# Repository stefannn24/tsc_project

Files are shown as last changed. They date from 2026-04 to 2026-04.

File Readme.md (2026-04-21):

InkTime Smartwatch

Hardware Functionality
Power Management

The power path begins at the USB-C connector (5V VBUS), which feeds the Li-Po charge management IC. This IC handles the safe charging cycle for the 250mAh battery. To ensure the MCU and E-paper display receive a clean and stable voltage even as the battery discharges, a DC/DC Buck/Boost regulator is utilized to provide a constant 3.3V system rail.
Compute & Connectivity

The system is driven by the nRF52840 SoC. It manages:

- I2C Bus: Used for communicating with the ultra-low-power IMU (Accelerometer).
- SPI Bus: Dedicated specifically to the E-paper display to ensure enough bandwidth for screen refreshes without interrupting other peripherals.
- USB: Routed directly to the nRF52840 for potential firmware flashing and USB-CDC communications.
- RF: A 50-ohm matched RF trace connects the MCU to a 2.4GHz Johanson SMD chip antenna for Bluetooth Low Energy (BLE) connectivity.

Peripherals

- Display: A low-power E-paper display module.
- IMU: An accelerometer is used for hardware-level step counting.
- Haptics

During the layout and routing phases of the PCB, several specific design rules and constraints were strictly applied to ensure manufacturability and signal integrity:

- Strict top-layer placement: To comply with manufacturing assembly constraints, 100% of the components were placed exclusively on the Top layer.
- Trace width constraints for power: All power delivery networks (VCC, VBUS, 3V3, VBAT) were manually routed using a minimum trace width of 0.3mm. This ensures adequate current handling, especially during peak loads from the shaker motor. Data signals were routed at 0.15mm.
- Antenna keepout zone: The 2.4GHz SMD antenna was placed strictly on the outer edge of the PCB. A complete keepout area was enforced underneath the antenna on all layers.
- Decoupling proximity: All 100nF (0201 package) decoupling capacitors were placed as physically close to the nRF52840 and IMU power pins as mechanically possible to filter out high-frequency switching noise.

(The complete machine-readable .bom and .cpl files are located in the /Manufacturing directory).

License
This project is licensed under the MIT License. See the LICENSE file for details.

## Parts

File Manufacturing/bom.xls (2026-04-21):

Comment | Designator | Footprint | JLCPCB Part#(optional)
1uF/50V | C15, C29, C30, C31, C32, C37, C38, EPD_C1, EPD_C2, EPD_C5, EPD_C6, EPD_C7, EPD_C8, EPD_C9, EPD_C10, EPD_C11, EPD_C12 | 0402 | C1518208
4.7uF/25V | C6, C14, C20, C21, C43, C2-EP-DR | 0402 | C5718966
10uF/25V | C1-EP-DR, C39 | 0603 | C344022
10uF/6.3V | C24 | 0402 | C76991
22uF/10V | C25, C33 | 0603 | C84419
100nF/25V | C5, C7, C8, C12, C19, C23, C27, C34, C42 | 0201 | C76939
100pF/50V | C11 | 0201 | C76922
47nF/16V | C16 | 0201 | C88917
12pF/50V | C1, C2, C17, C18 | 0201 | C384960
1pf/50V | C3, C4 | 0201 | C161411
0Ω | R2, R3, R4 | 0201 | C106227
470mΩ | R1_EP_DR | 0201 | C4327454
2.2Ω | R_TYPE_SEL | 0201 | C138154
3.3KΩ | R17, R18 | 0201 | C851731
5.1KΩ | R1_USB, R2_USB | 0201 | C852257
10KΩ | R5, R7, R8, R9, R2_EP_DR, R_PWR_EPD | 0201 | C1882653
470nH | L7 | 2520 | C5832368
3.9nH | L1 | 0201 | C77115
10uH | L2 | 0603 | C275361
15nH | L3 | 0402 | C576527
68uH | L5 | SMD, 4.8x4.8mm | C2045671
USBLC6-2SC6Y | D3 | SOT-23-6L | C2969755
KH-TYPE-C-16P | J4 | SMD | C709357
5034802400 | J1 | SMD, P=0.5mm | C122434
MAX17048G+T10 | U3 | DFN-8-EP(2x2) | C2682616
EVPAKE31A | SW_UP, SW_ENT, SW_DN | SMD,3.9x2.9mm | C569760
DRV2605YZFR | IC2 | DSBGA-9 | C81079
DMG2305UX-7 | Q1 | SOT-23 | C150470
SI1308EDL-T1-GE3 | Q3 | SOT-323 | C469327
MBR0530 | D2, D4, D5 | SOD-123 | C699108
BMA421 | IC3 | LGA-12(2x2) | C5242966
RT6160AWSC | IC9 | WLCSP-15B(2.3x1.4) | C7065276
BQ25180YBGR | IC1 | DSBGA-8(1.1x1.6) | C3682423
2450AT18B100E | ANT1 | 1206 | C2917717
NRF52840-QIAA-R | U1 | AQFN-73-EP(7x7) | C190794
X1A0000910005 | X2 | SMD3215-2P | C255869
Q22FA12800025 | X1 | SMD2016-4P | C187794

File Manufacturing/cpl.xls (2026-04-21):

ANT1 | 42.80 | 18.10 | 0.00 | 2450AT18B100E | 2450AT18B100E_ANTC3216X140N
C1 | 32.90 | 23.20 | 90.00 | 12pF | NORDIC_NRF_3_RESC0201_N
C1-EP-DR | 20.60 | 21.50 | 90.00 | 10uF | NORDIC_NRF_3_RESC0402_N
C10 | 35.00 | 18.10 | 180.00 | N.C. | NORDIC_NRF_3_RESC0201_N
C11 | 34.80 | 19.30 | 180.00 | 100pF | NORDIC_NRF_3_RESC0201_N
C12 | 32.40 | 20.80 | 270.00 | 100nF | NORDIC_NRF_3_RESC0201_N
C13 | 31.20 | 20.80 | 270.00 | N.C. | NORDIC_NRF_3_RESC0201_N
C14 | 25.70 | 21.50 | 270.00 | 4.7uF | NORDIC_NRF_3_RESC0402_N
C15 | 30.50 | 22.40 | 0.00 | 1uF | NORDIC_NRF_3_RESC0402_N
C16 | 30.40 | 21.10 | 270.00 | 47nF | NORDIC_NRF_3_RESC0201_N
C17 | 23.00 | 17.60 | 0.00 | 12pF | NORDIC_NRF_3_RESC0201_N
C18 | 23.30 | 15.90 | 0.00 | 12pF | NORDIC_NRF_3_RESC0201_N
C19 | 19.40 | 9.70 | 0.00 | 100nF | NORDIC_NRF_3_RESC0201_N
C2 | 36.50 | 19.80 | 0.00 | 12pF | NORDIC_NRF_3_RESC0201_N
C2-EP-DR | 14.40 | 25.50 | 270.00 | 4.7uF/25V | NORDIC_NRF_3_RESC0402_N
C20 | 25.20 | 12.80 | 180.00 | 4.7uF | NORDIC_NRF_3_RESC0402_N
C21 | 27.40 | 11.40 | 270.00 | 1uF | NORDIC_NRF_3_RESC0402_N
C22 | 39.70 | 18.30 | 90.00 | N.C. | NORDIC_NRF_3_RESC0201_N
C23 | 23.10 | 25.70 | 180.00 | 0.1uF | NORDIC_NRF_3_RESC0201_N
C24 | 21.10 | 25.70 | 0.00 | 10uF | NORDIC_NRF_3_RESC0402_N
C25 | 18.70 | 22.80 | 90.00 | 22uF | NORDIC_NRF_3_RESC0603_N
C27 | 13.70 | 29.90 | 90.00 | 0.1uF | NORDIC_NRF_3_RESC0201_N
C29 | 11.80 | 5.70 | 0.00 | 1uF | NORDIC_NRF_3_RESC0402_N
C3 | 35.30 | 16.90 | 180.00 | 1pF | NORDIC_NRF_3_RESC0201_N
C30 | 34.10 | 5.90 | 180.00 | 1uF | NORDIC_NRF_3_RESC0402_N
C31 | 23.10 | 5.60 | 180.00 | 1uF | NORDIC_NRF_3_RESC0402_N
C32 | 23.50 | 9.70 | 180.00 | 1uF | NORDIC_NRF_3_RESC0402_N
C33 | 22.20 | 19.70 | 270.00 | 22uF | NORDIC_NRF_3_RESC0603_N
C34 | 19.20 | 8.50 | 180.00 | 0.1uF | NORDIC_NRF_3_RESC0201_N
C37 | 14.20 | 28.10 | 180.00 | 1uF | NORDIC_NRF_3_RESC0402_N
C38 | 17.40 | 24.20 | 270.00 | 1uF | NORDIC_NRF_3_RESC0402_N
C39 | 16.10 | 25.60 | 270.00 | 10uF | NORDIC_NRF_3_RESC0603_N
C4 | 38.60 | 17.10 | 90.00 | 1pF | NORDIC_NRF_3_RESC0201_N
C42 | 25.40 | 27.00 | 270.00 | 0.1uF | NORDIC_NRF_3_RESC0201_N
C43 | 20.30 | 27.00 | 180.00 | 4.7uF | NORDIC_NRF_3_RESC0402_N
C5 | 24.70 | 19.60 | 180.00 | 100nF | NORDIC_NRF_3_RESC0201_N
C6 | 25.10 | 14.20 | 180.00 | 4.7uF | NORDIC_NRF_3_RESC0402_N
C7 | 30.30 | 11.90 | 270.00 | 100nF | NORDIC_NRF_3_RESC0201_N
C8 | 31.50 | 12.00 | 270.00 | 100nF | NORDIC_NRF_3_RESC0201_N
C9 | 34.90 | 15.70 | 180.00 | 820pF | NORDIC_NRF_3_RESC0201_N
D2 | 17.60 | 17.50 | 270.00 | MBR0530 | ESP32_C6_LIBRARY_5_SOD3716X135N
D3 | 23.30 | 31.50 | 0.00 | USBLC6-2SC6Y | ESP32_C6_LIBRARY_3_SOT95P280X145-6N
D4 | 15.90 | 20.60 | 90.00 | MBR0530 | ESP32_C6_LIBRARY_5_SOD3716X135N
D5 | 16.20 | 14.00 | 90.00 | MBR0530 | ESP32_C6_LIBRARY_5_SOD3716X135N
EPD_C1 | 13.70 | 20.00 | 180.00 | 1uF/50V | NORDIC_NRF_3_RESC0402_N
EPD_C10 | 12.90 | 10.50 | 180.00 | 1uF/50V | NORDIC_NRF_3_RESC0402_N
EPD_C11 | 12.90 | 9.10 | 180.00 | 1uF/50V | NORDIC_NRF_3_RESC0402_N
EPD_C12 | 10.80 | 10.10 | 90.00 | 1uF/50V | NORDIC_NRF_3_RESC0402_N
EPD_C2 | 13.70 | 21.30 | 180.00 | 1uF/50V | NORDIC_NRF_3_RESC0402_N
EPD_C5 | 13.00 | 17.00 | 180.00 | 0.1uF/50V | NORDIC_NRF_3_RESC0402_N
EPD_C6 | 13.00 | 15.70 | 180.00 | 1uF/50V | NORDIC_NRF_3_RESC0402_N
EPD_C7 | 13.00 | 14.40 | 180.00 | 1uF/50V | NORDIC_NRF_3_RESC0402_N
EPD_C8 | 13.00 | 13.10 | 180.00 | 1uF/50V | NORDIC_NRF_3_RESC0402_N
EPD_C9 | 12.90 | 11.80 | 180.00 | 1uF/50V | NORDIC_NRF_3_RESC0402_N
IC1 | 17.20 | 26.30 | 180.00 | BQ25180YBGR | BQ25180YBGR_BGA8C40P2X4_100X155X50
IC2 | 21.20 | 9.30 | 270.00 | DRV2605YZFR | DRV2605YZFR_BGA9C50P3X3_144X144X62
IC3 | 19.75 | 11.85 | 90.00 | BMA421 | BMA423_BMA423
IC9 | 22.60 | 23.85 | 0.00 | RT6160AWSC_RT6160AWSC | RT6160AWSC_BGA15C40P3X5_140X230X60
J1 | 9.30 | 17.25 | 270.00 | 503480-2400 | 503480-2400_5034802400
J2 | 41.52 | 8.70 | 0.00 | TC2030-IDC_TC2030-IDC | TC2030-IDC_TC2030IDC
J4 | 23.00 | 30.94 | 180.00 | KH-TYPE-C-16P | KH-TYPE-C-16P_KINGHELM_KH-TYPE-C-16P
L1 | 37.70 | 18.60 | 0.00 | 3.9nH | NORDIC_NRF_2_RESC0402_L
L2 | 27.90 | 21.10 | 90.00 | 10uH | NORDIC_NRF_2_RESC0603_N
L3 | 27.50 | 23.70 | 0.00 | 15nH | NORDIC_NRF_2_RESC0402_L
L5 | 6.50 | 30.55 | 0.00 | 68uH | ESP32_C6_LIBRARY_2_IND_4828-WE-TPC_WRE
L7 | 27.30 | 25.90 | 270.00 | FTC252012SR47MBCA | MLP2016SR47MT0S1_INDC2016X100N
Q1 | 32.65 | 29.40 | 270.00 | 20V/4.2A/52mΩ/1.4W | ESP32_C6_LIBRARY_4_ESP32_C6_LIBRARY_4_ESP32_C6_LIBRARY_4_ESP32_C6_LIBRARY_4_ESP32_WROVER_SPARKFUN-DISCRETESEMI_SOT23-3
Q3 | 13.50 | 23.40 | 0.00 | SI1308EDL-T1-GE3 | ESP32_C6_LIBRARY_6_SOT65P210X110-3N
R17 | 20.85 | 14.90 | 0.00 | 3K3 | CPF0201D7K68C1_0201
R18 | 19.10 | 15.50 | 0.00 | 3K3 | CPF0201D7K68C1_0201
R1_EP_DR | 5.10 | 26.30 | 0.00 | 0.47 | CPF0201D7K68C1_0201
R1_USB | 24.10 | 27.20 | 270.00 | 5K1 | CPF0201D7K68C1_0201
R2 | 21.70 | 22.10 | 0.00 | 0 | CPF0201D7K68C1_0201
R2_EP_DR | 3.90 | 26.00 | 0.00 | 10k | CPF0201D7K68C1_0201
R2_USB | 22.60 | 27.20 | 90.00 | 5K1 | CPF0201D7K68C1_0201
R3 | 21.80 | 10.75 | 270.00 | 0 | CPF0201D7K68C1_0201
R4 | 21.05 | 23.90 | 0.00 | 0 | CPF0201D7K68C1_0201
R5 | 32.30 | 6.10 | 180.00 | 10K | CPF0201D7K68C1_0201
R7 | 11.80 | 6.90 | 90.00 | 10K | CPF0201D7K68C1_0201
R8 | 20.30 | 4.40 | 0.00 | 10K | CPF0201D7K68C1_0201
R9 | 16.90 | 28.00 | 90.00 | 10k | CPF0201D7K68C1_0201
R_PWR_EPD | 29.70 | 29.00 | 270.00 | 10k | CPF0201D7K68C1_0201
R_TYPE_SEL | 6.40 | 26.40 | 180.00 | 2.2 | CPF0201D7K68C1_0201
SJ1 | 9.10 | 26.10 | 180.00 |  | ESP32_C6_LIBRARY_7_JUMPER_SJ
SW_DN | 12.00 | 3.37 | 180.00 | 2025-10-22_07-23-44_LIBRARY_EVP-AKE31ASW_EVP-AKE31A_PAN | 2025-10-22_07-23-44_LIBRARY_SW_EVP-AKE31A_PAN
SW_ENT | 23.00 | 3.37 | 180.00 | 2025-10-22_07-23-44_LIBRARY_EVP-AKE31ASW_EVP-AKE31A_PAN | 2025-10-22_07-23-44_LIBRARY_SW_EVP-AKE31A_PAN
SW_UP | 34.00 | 3.37 | 180.00 | 2025-10-22_07-23-44_LIBRARY_EVP-AKE31ASW_EVP-AKE31A_PAN | 2025-10-22_07-23-44_LIBRARY_SW_EVP-AKE31A_PAN
TP_3.3V1 | 23.70 | 21.50 | 0.00 | HECTOR_WATCH_1_TPTP20R | HECTOR_WATCH_1_TP20R
TP_3V1 | 18.95 | 17.50 | 0.00 | HECTOR_WATCH_1_TPTP20R | HECTOR_WATCH_1_TP20R
TP_BAT_GND | 15.90 | 32.40 | 0.00 | HECTOR_WATCH_1_TPTP20R | HECTOR_WATCH_1_TP20R
TP_GND | 28.90 | 6.25 | 180.00 | HECTOR_WATCH_1_TPTP20R | HECTOR_WATCH_1_TP20R
TP_ON | 20.60 | 7.10 | 180.00 | HECTOR_WATCH_1_TPTP20R | HECTOR_WATCH_1_TP20R
TP_OP | 23.10 | 7.70 | 180.00 | HECTOR_WATCH_1_TPTP20R | HECTOR_WATCH_1_TP20R
TP_RESET1 | 29.00 | 9.35 | 0.00 | HECTOR_WATCH_1_TPTP20R | HECTOR_WATCH_1_TP20R
TP_SCL1 | 21.30 | 16.70 | 0.00 | HECTOR_WATCH_1_TPTP20R | HECTOR_WATCH_1_TP20R
TP_SDA1 | 31.85 | 25.70 | 0.00 | HECTOR_WATCH_1_TPTP20R | HECTOR_WATCH_1_TP20R
TP_SWDCLK1 | 37.10 | 14.65 | 0.00 | HECTOR_WATCH_1_TPTP20R | HECTOR_WATCH_1_TP20R
TP_SWDIO1 | 34.95 | 13.10 | 180.00 | HECTOR_WATCH_1_TPTP20R | HECTOR_WATCH_1_TP20R
TP_SWO1 | 33.35 | 10.75 | 0.00 | HECTOR_WATCH_1_TPTP20R | HECTOR_WATCH_1_TP20R
TP_VBAT | 16.20 | 29.70 | 0.00 | HECTOR_WATCH_1_TPTP20R | HECTOR_WATCH_1_TP20R
TP_VREG | 24.70 | 23.95 | 0.00 | HECTOR_WATCH_1_TPTP20R | HECTOR_WATCH_1_TP20R
U1 | 30.10 | 16.35 | 0.00 | NRF52840_QF | NORDIC_NRF_4_AQFN50P700X700X85_HS-74N
U3 | 11.50 | 31.50 | 180.00 | MAX17048G+T10 | ESP32_C6_LIBRARY_SON50P200X200X80-9N
X1 | 34.70 | 21.80 | 270.00 | 32MHZ | NORDIC_NRF_BT-XTAL_2016_N
X2\ | 25.30 | 16.95 | 270.00 | 32.768kHz | NORDIC_NRF_1_XTAL_3215_N

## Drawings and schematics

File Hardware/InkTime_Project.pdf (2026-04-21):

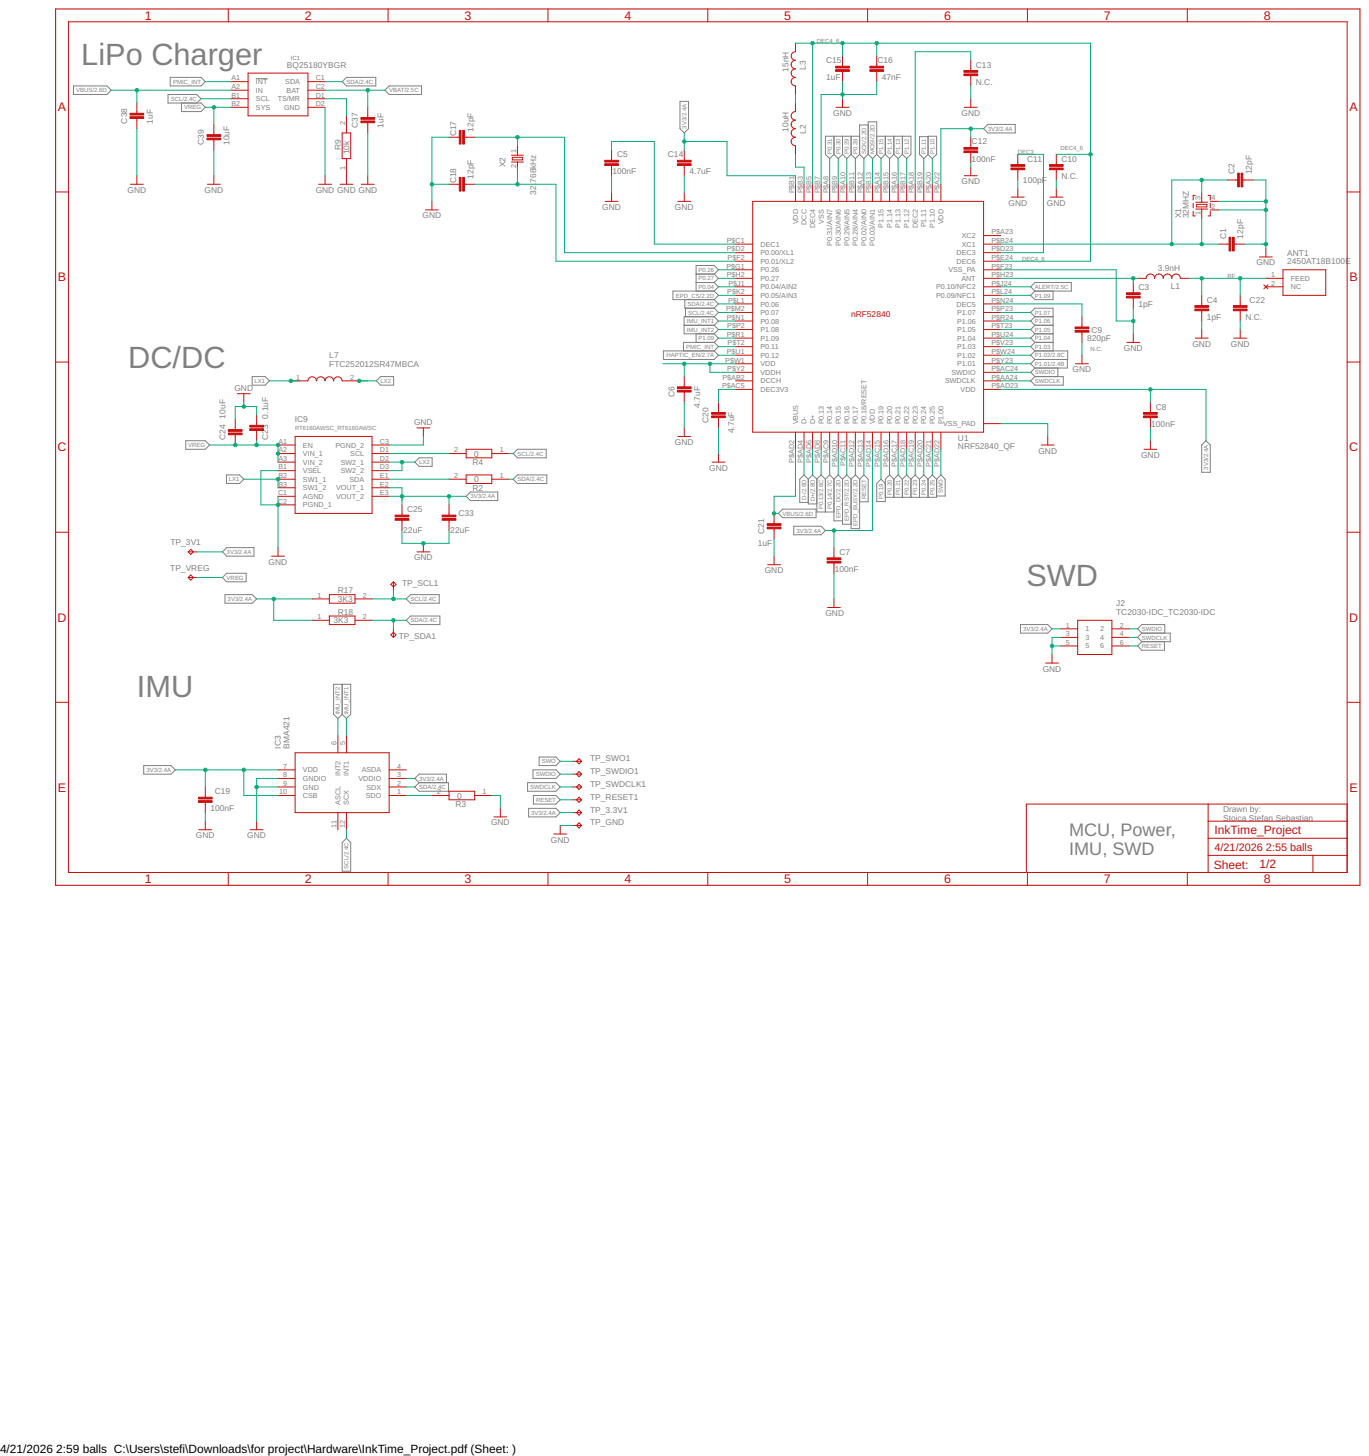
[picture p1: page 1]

4/21/2026 2:59 balls C:\Users\stefi\Downloads\for project\Hardware\InkTime_Project.pdf (Sheet: )

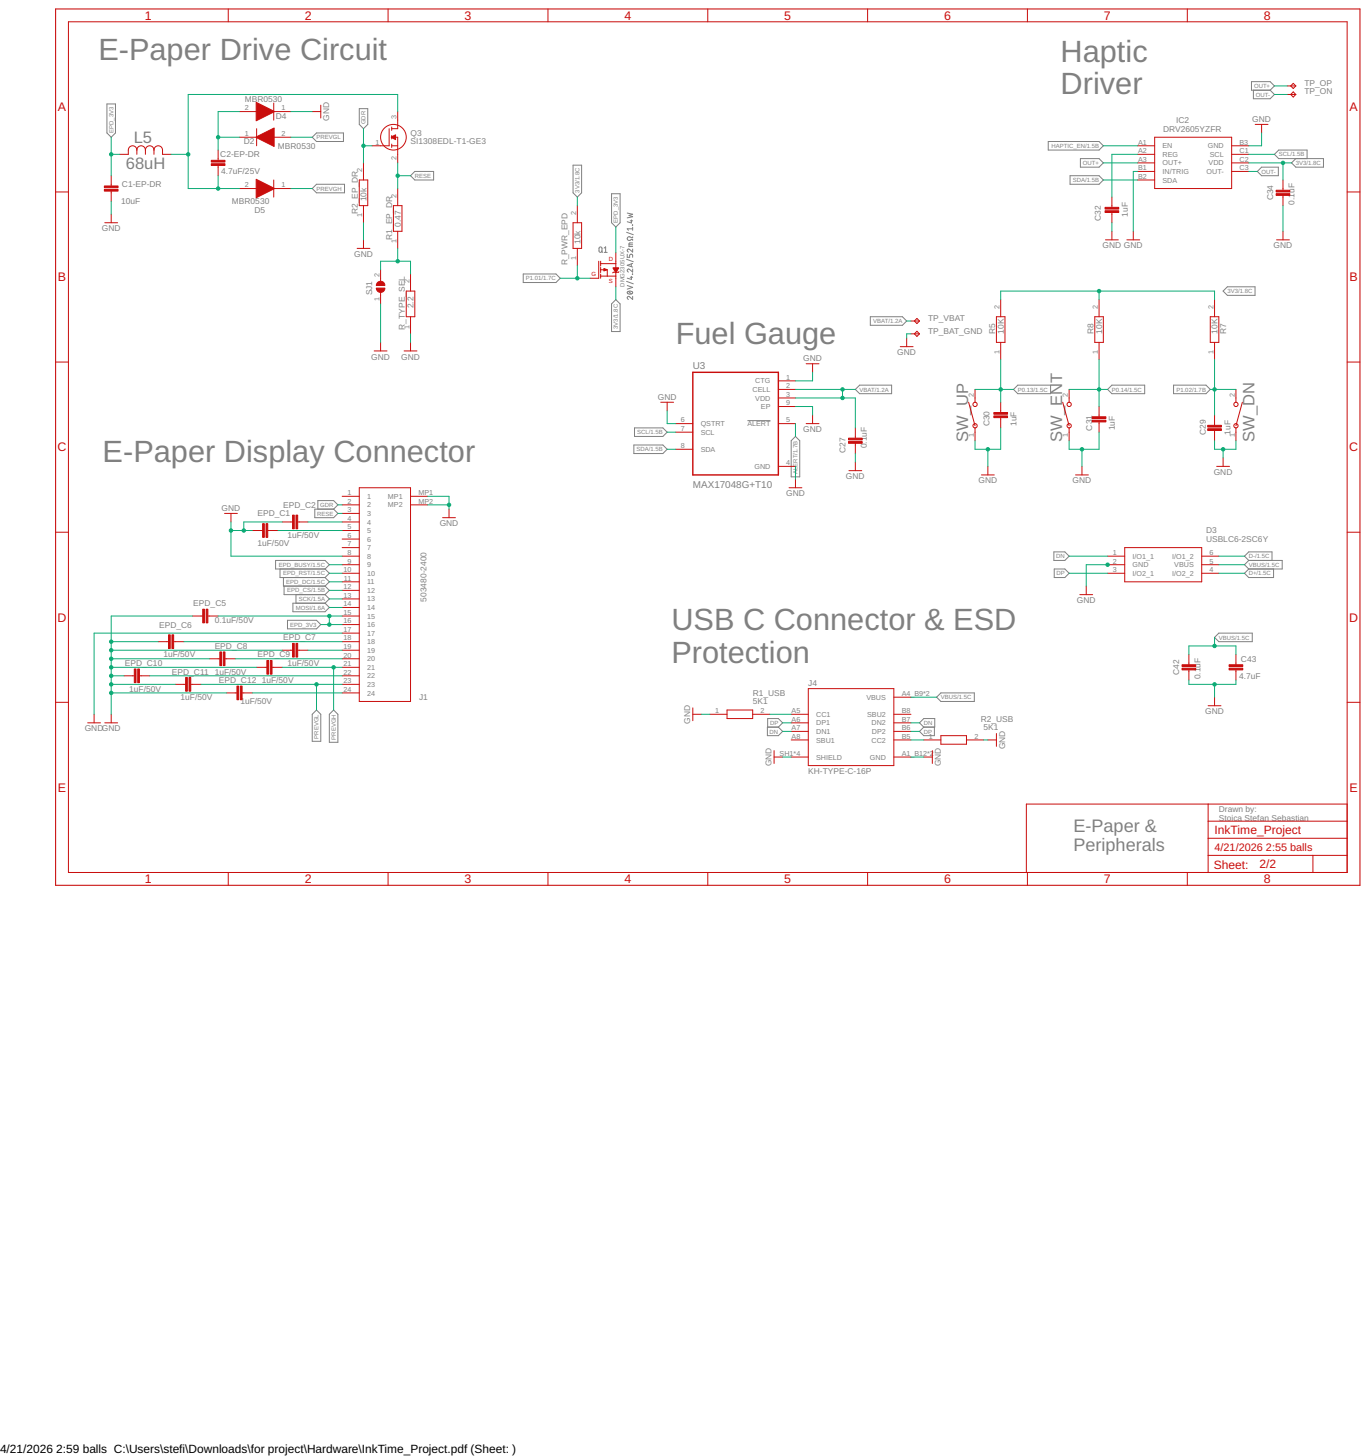
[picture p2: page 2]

EPD_C7 18

EPD_C8 | 19

1uF/50V | EPD_C9 | 20
EPD_C11 1uF/50V | | 22

EPD_C10 | | 1uF/50V 21

EPD_C12 1uF/50V | 23

4/21/2026 2:59 balls C:\Users\stefi\Downloads\for project\Hardware\InkTime_Project.pdf (Sheet: )

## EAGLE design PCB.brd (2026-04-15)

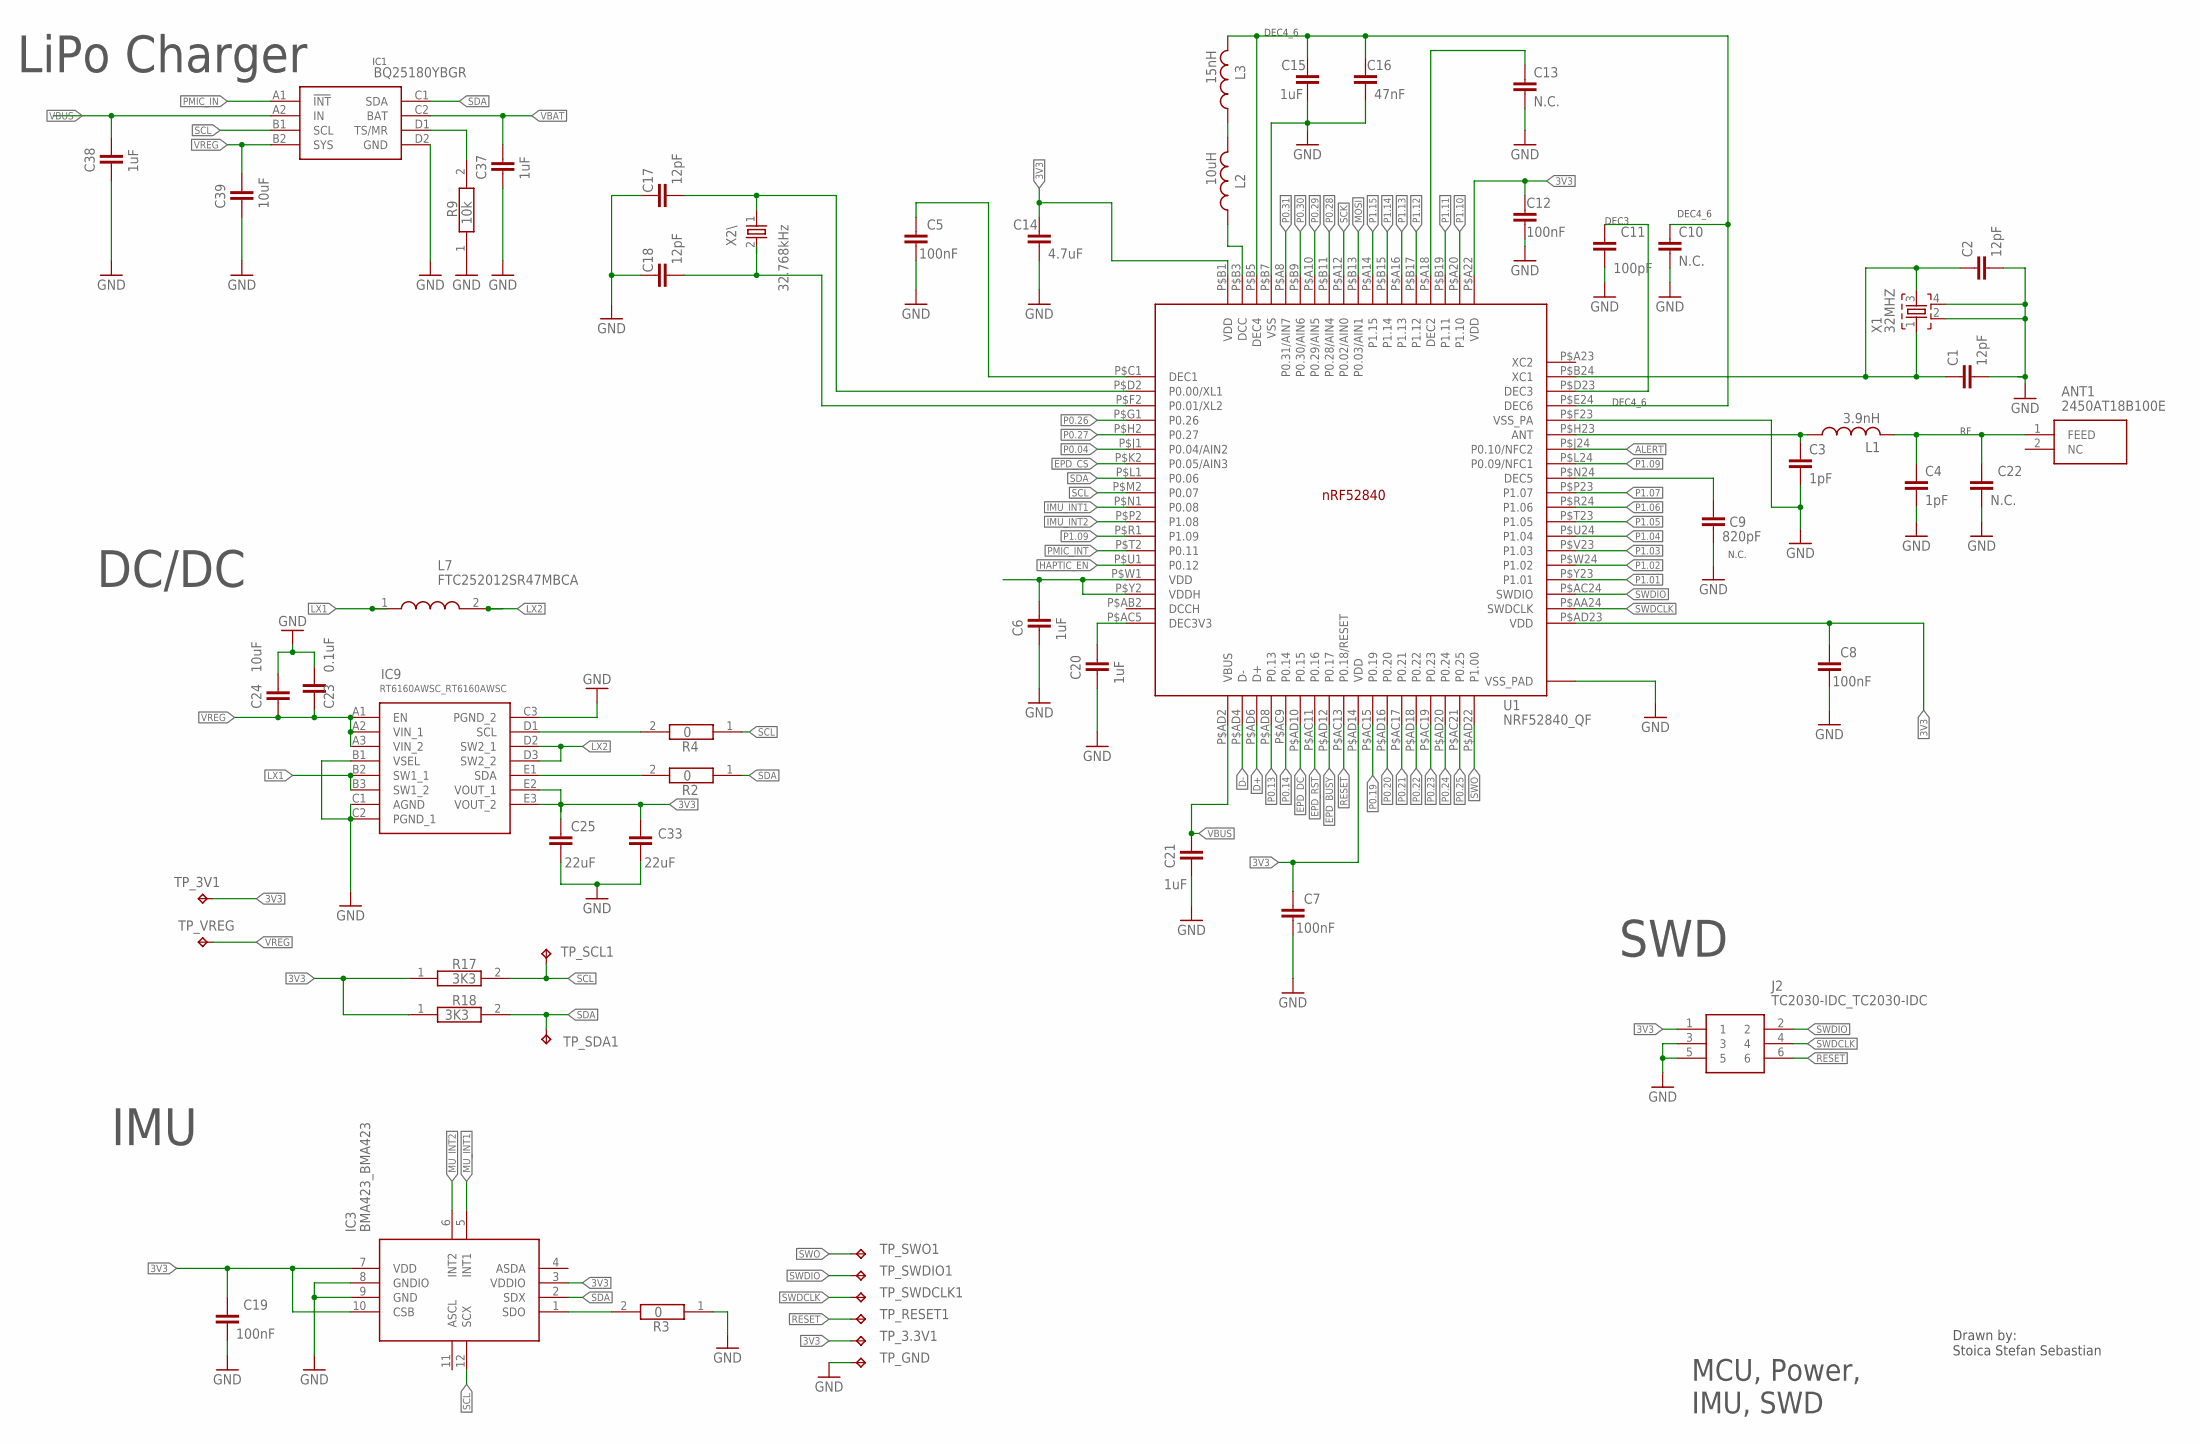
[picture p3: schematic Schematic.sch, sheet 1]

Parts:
ANT1: 2450AT18B100E; 2450AT18B100E_ANTC3216X140N
C1, C2, C17, C18: 12pF; NORDIC_NRF_3_RESC0201_N
C3, C4: 1pF; NORDIC_NRF_3_RESC0201_N
C5, C7, C8, C12, C19: 100nF; NORDIC_NRF_3_RESC0201_N
C6, C15, C20, C21, C37, C38: 1uF; NORDIC_NRF_3_RESC0402_N
C9: 820pF; NORDIC_NRF_3_RESC0201_N
C10, C13, C22: N.C.; NORDIC_NRF_3_RESC0201_N
C11: 100pF; NORDIC_NRF_3_RESC0201_N
C14: 4.7uF; NORDIC_NRF_3_RESC0402_N
C16: 47nF; NORDIC_NRF_3_RESC0201_N
C23: 0.1uF; NORDIC_NRF_3_RESC0201_N
C24, C39: 10uF; NORDIC_NRF_3_RESC0402_N
C25, C33: 22uF; NORDIC_NRF_3_RESC0402_N
IC1: BQ25180YBGR; BQ25180YBGR_BGA8C40P2X4_100X155X50
IC3: BMA423_BMA423
IC9: RT6160AWSC_RT6160AWSC; RT6160AWSC_BGA15C40P3X5_140X230X60
J2: TC2030-IDC_TC2030-IDC; TC2030-IDC_TC2030IDC
L1: 3.9nH; NORDIC_NRF_2_RESC0402_L
L2: 10uH; NORDIC_NRF_2_RESC0402_L
L3: 15nH; NORDIC_NRF_2_RESC0402_L
L7: FTC252012SR47MBCA; MLP2016SR47MT0S1_INDC2016X100N
R2, R3, R4: 0; CPF0201D7K68C1_0201
R9: 10k; CPF0201D7K68C1_0201
R17, R18: 3K3; CPF0201D7K68C1_0201
TP_3.3V1, TP_3V1: HECTOR_WATCH_1_TPTP20R; HECTOR_WATCH_1_TP20R
TP_GND: HECTOR_WATCH_1_TPTP20R; HECTOR_WATCH_1_TP20R
TP_RESET1: HECTOR_WATCH_1_TPTP20R; HECTOR_WATCH_1_TP20R
TP_SCL1: HECTOR_WATCH_1_TPTP20R; HECTOR_WATCH_1_TP20R
TP_SDA1: HECTOR_WATCH_1_TPTP20R; HECTOR_WATCH_1_TP20R
TP_SWDCLK1: HECTOR_WATCH_1_TPTP20R; HECTOR_WATCH_1_TP20R
TP_SWDIO1: HECTOR_WATCH_1_TPTP20R; HECTOR_WATCH_1_TP20R
TP_SWO1: HECTOR_WATCH_1_TPTP20R; HECTOR_WATCH_1_TP20R
TP_VREG: HECTOR_WATCH_1_TPTP20R; HECTOR_WATCH_1_TP20R
U1: NRF52840_QF; NORDIC_NRF_4_AQFN50P700X700X85_HS-74N
X1: 32MHZ; NORDIC_NRF_BT-XTAL_2016_N
X2\: 32.768kHz; NORDIC_NRF_1_XTAL_3215_N

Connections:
3V3: C6.1, C7.1, C8.1, C12.2, C14.1, C19.2, C25.1, C33.1, IC3.3 (VDDIO), IC3.7 (VDD), IC3.10 (CSB), IC9.E2 (VOUT_1), IC9.E3 (VOUT_2), J2.1, R17.1, R18.1, TP_3.3V1.TP, TP_3V1.TP, U1.P$A22 (VDD), U1.P$AD14 (VDD), U1.P$AD23 (VDD), U1.P$B1 (VDD), U1.P$W1 (VDD), U1.P$Y2 (VDDH); also elsewhere on the board
ALERT: U1.P$J24 (P0.10/NFC2); also elsewhere on the board
D+: U1.P$AD6 (D+); also elsewhere on the board
D-: U1.P$AD4 (D-); also elsewhere on the board
EPD_BUSY: U1.P$AD12 (P0.17); also elsewhere on the board
EPD_CS: U1.P$K2 (P0.05/AIN3); also elsewhere on the board
EPD_DC: U1.P$AD10 (P0.15); also elsewhere on the board
EPD_RST: U1.P$AC11 (P0.16); also elsewhere on the board
GND: C1.2, C2.2, C3.1, C4.1, C5.2, C6.2, C7.2, C8.2, C9.1, C10.1, C11.1, C12.1, C13.1, C14.2, C15.2, C16.1, C17.1, C18.1, C19.1, C20.2, C21.2, C22.1, C23.1, C24.1, C25.2, C33.2, C37.2, C38.2, C39.2, IC1.D2 (GND), IC3.8 (GNDIO), IC3.9 (GND), IC9.B1 (VSEL), IC9.C1 (AGND), IC9.C2 (PGND_1), IC9.C3 (PGND_2), J2.3, J2.5, R3.1, R9.1, TP_GND.TP, U1.P$74 (VSS_PAD), U1.P$75 (VSS_PAD), U1.P$76 (VSS_PAD), U1.P$77 (VSS_PAD), U1.P$78 (VSS_PAD), U1.P$79 (VSS_PAD), U1.P$80 (VSS_PAD), U1.P$81 (VSS_PAD), U1.P$82 (VSS_PAD), U1.P$83 (VSS_PAD), U1.P$84 (VSS_PAD), U1.P$85 (VSS_PAD), U1.P$86 (VSS_PAD), U1.P$87 (VSS_PAD), U1.P$88 (VSS_PAD), U1.P$89 (VSS_PAD), U1.P$90 (VSS_PAD), U1.P$B7 (VSS), U1.P$F23 (VSS_PA), X1.2, X1.4; also elsewhere on the board
HAPTIC_EN: U1.P$U1 (P0.12); also elsewhere on the board
IMU_INT1: U1.P$N1 (P0.08)
IMU_INT2: U1.P$P2 (P1.08)
LX1: IC9.B2 (SW1_1), IC9.B3 (SW1_2), L7.1
LX2: IC9.D2 (SW2_1), IC9.D3 (SW2_2), L7.2
MOSI: U1.P$B13 (P0.03/AIN1); also elsewhere on the board
MU_INT1: IC3.5 (INT1)
MU_INT2: IC3.6 (INT2)
unnamed: C3.2, L1.1, U1.P$H23 (ANT)
unnamed: ANT1.1 (FEED), C4.2, C22.2, L1.2
unnamed: C11.2, U1.P$D23 (DEC3)
unnamed: C1.1, C2.1, U1.P$B24 (XC1), X1.1, X1.3
unnamed: C9.2, U1.P$N24 (DEC5)
unnamed: L2.1, U1.P$B3 (DCC)
unnamed: IC1.D1 (TS/MR), R9.2
unnamed: IC9.D1 (SCL), R4.2
unnamed: IC9.E1 (SDA), R2.2
unnamed: IC3.1 (SDO), R3.2
unnamed: C5.1, U1.P$C1 (DEC1)
unnamed: C17.2, U1.P$D2 (P0.00/XL1), X2\.1
unnamed: C20.1, U1.P$AC5 (DEC3V3)
unnamed: C18.2, U1.P$F2 (P0.01/XL2), X2\.2
unnamed: L2.2, L3.1
unnamed: C10.2, C15.1, C16.2, L3.2, U1.P$B5 (DEC4), U1.P$E24 (DEC6)
unnamed: C13.2, U1.P$A18 (DEC2)
P0.04: U1.P$J1 (P0.04/AIN2)
P0.13: U1.P$AD8 (P0.13); also elsewhere on the board
P0.14: U1.P$AC9 (P0.14); also elsewhere on the board
P0.19: U1.P$AC15 (P0.19)
P0.20: U1.P$AD16 (P0.20)
P0.21: U1.P$AC17 (P0.21)
P0.22: U1.P$AD18 (P0.22)
P0.23: U1.P$AC19 (P0.23)
P0.24: U1.P$AD20 (P0.24)
P0.25: U1.P$AC21 (P0.25)
P0.26: U1.P$G1 (P0.26)
P0.27: U1.P$H2 (P0.27)
P0.28: U1.P$B11 (P0.28/AIN4)
P0.29: U1.P$A10 (P0.29/AIN5)
P0.30: U1.P$B9 (P0.30/AIN6)
P0.31: U1.P$A8 (P0.31/AIN7)
P1.01: U1.P$Y23 (P1.01); also elsewhere on the board
P1.02: U1.P$W24 (P1.02); also elsewhere on the board
P1.03: U1.P$V23 (P1.03)
P1.04: U1.P$U24 (P1.04)
P1.05: U1.P$T23 (P1.05)
P1.06: U1.P$R24 (P1.06)
P1.07: U1.P$P23 (P1.07)
P1.09: U1.P$L24 (P0.09/NFC1), U1.P$R1 (P1.09)
P1.10: U1.P$A20 (P1.10)
P1.11: U1.P$B19 (P1.11)
P1.12: U1.P$B17 (P1.12)
P1.13: U1.P$A16 (P1.13)
P1.14: U1.P$B15 (P1.14)
P1.15: U1.P$A14 (P1.15)
PMIC_IN: IC1.A1 (!INT)
PMIC_INT: U1.P$T2 (P0.11)
RESET: J2.6, TP_RESET1.TP, U1.P$AC13 (P0.18/RESET)
SCK: U1.P$A12 (P0.02/AIN0); also elsewhere on the board
SCL: IC1.B1 (SCL), IC3.12 (SCX), R4.1, R17.2, TP_SCL1.TP, U1.P$M2 (P0.07); also elsewhere on the board
SDA: IC1.C1 (SDA), IC3.2 (SDX), R2.1, R18.2, TP_SDA1.TP, U1.P$L1 (P0.06); also elsewhere on the board
SWDCLK: J2.4, TP_SWDCLK1.TP, U1.P$AA24 (SWDCLK)
SWDIO: J2.2, TP_SWDIO1.TP, U1.P$AC24 (SWDIO)
SWO: TP_SWO1.TP, U1.P$AD22 (P1.00)
VBAT: C37.1, IC1.C2 (BAT); also elsewhere on the board
VBUS: C21.1, C38.1, IC1.A2 (IN), U1.P$AD2 (VBUS); also elsewhere on the board
VREG: C23.2, C24.2, C39.1, IC1.B2 (SYS), IC9.A1 (EN), IC9.A2 (VIN_1), IC9.A3 (VIN_2), TP_VREG.TP

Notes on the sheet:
DC/DC
SWD
N.C.
DEC3
DEC4_6
LiPo Charger
IMU
Drawn by: Stoica Stefan Sebastian
IC1
MCU, Power, IMU, SWD

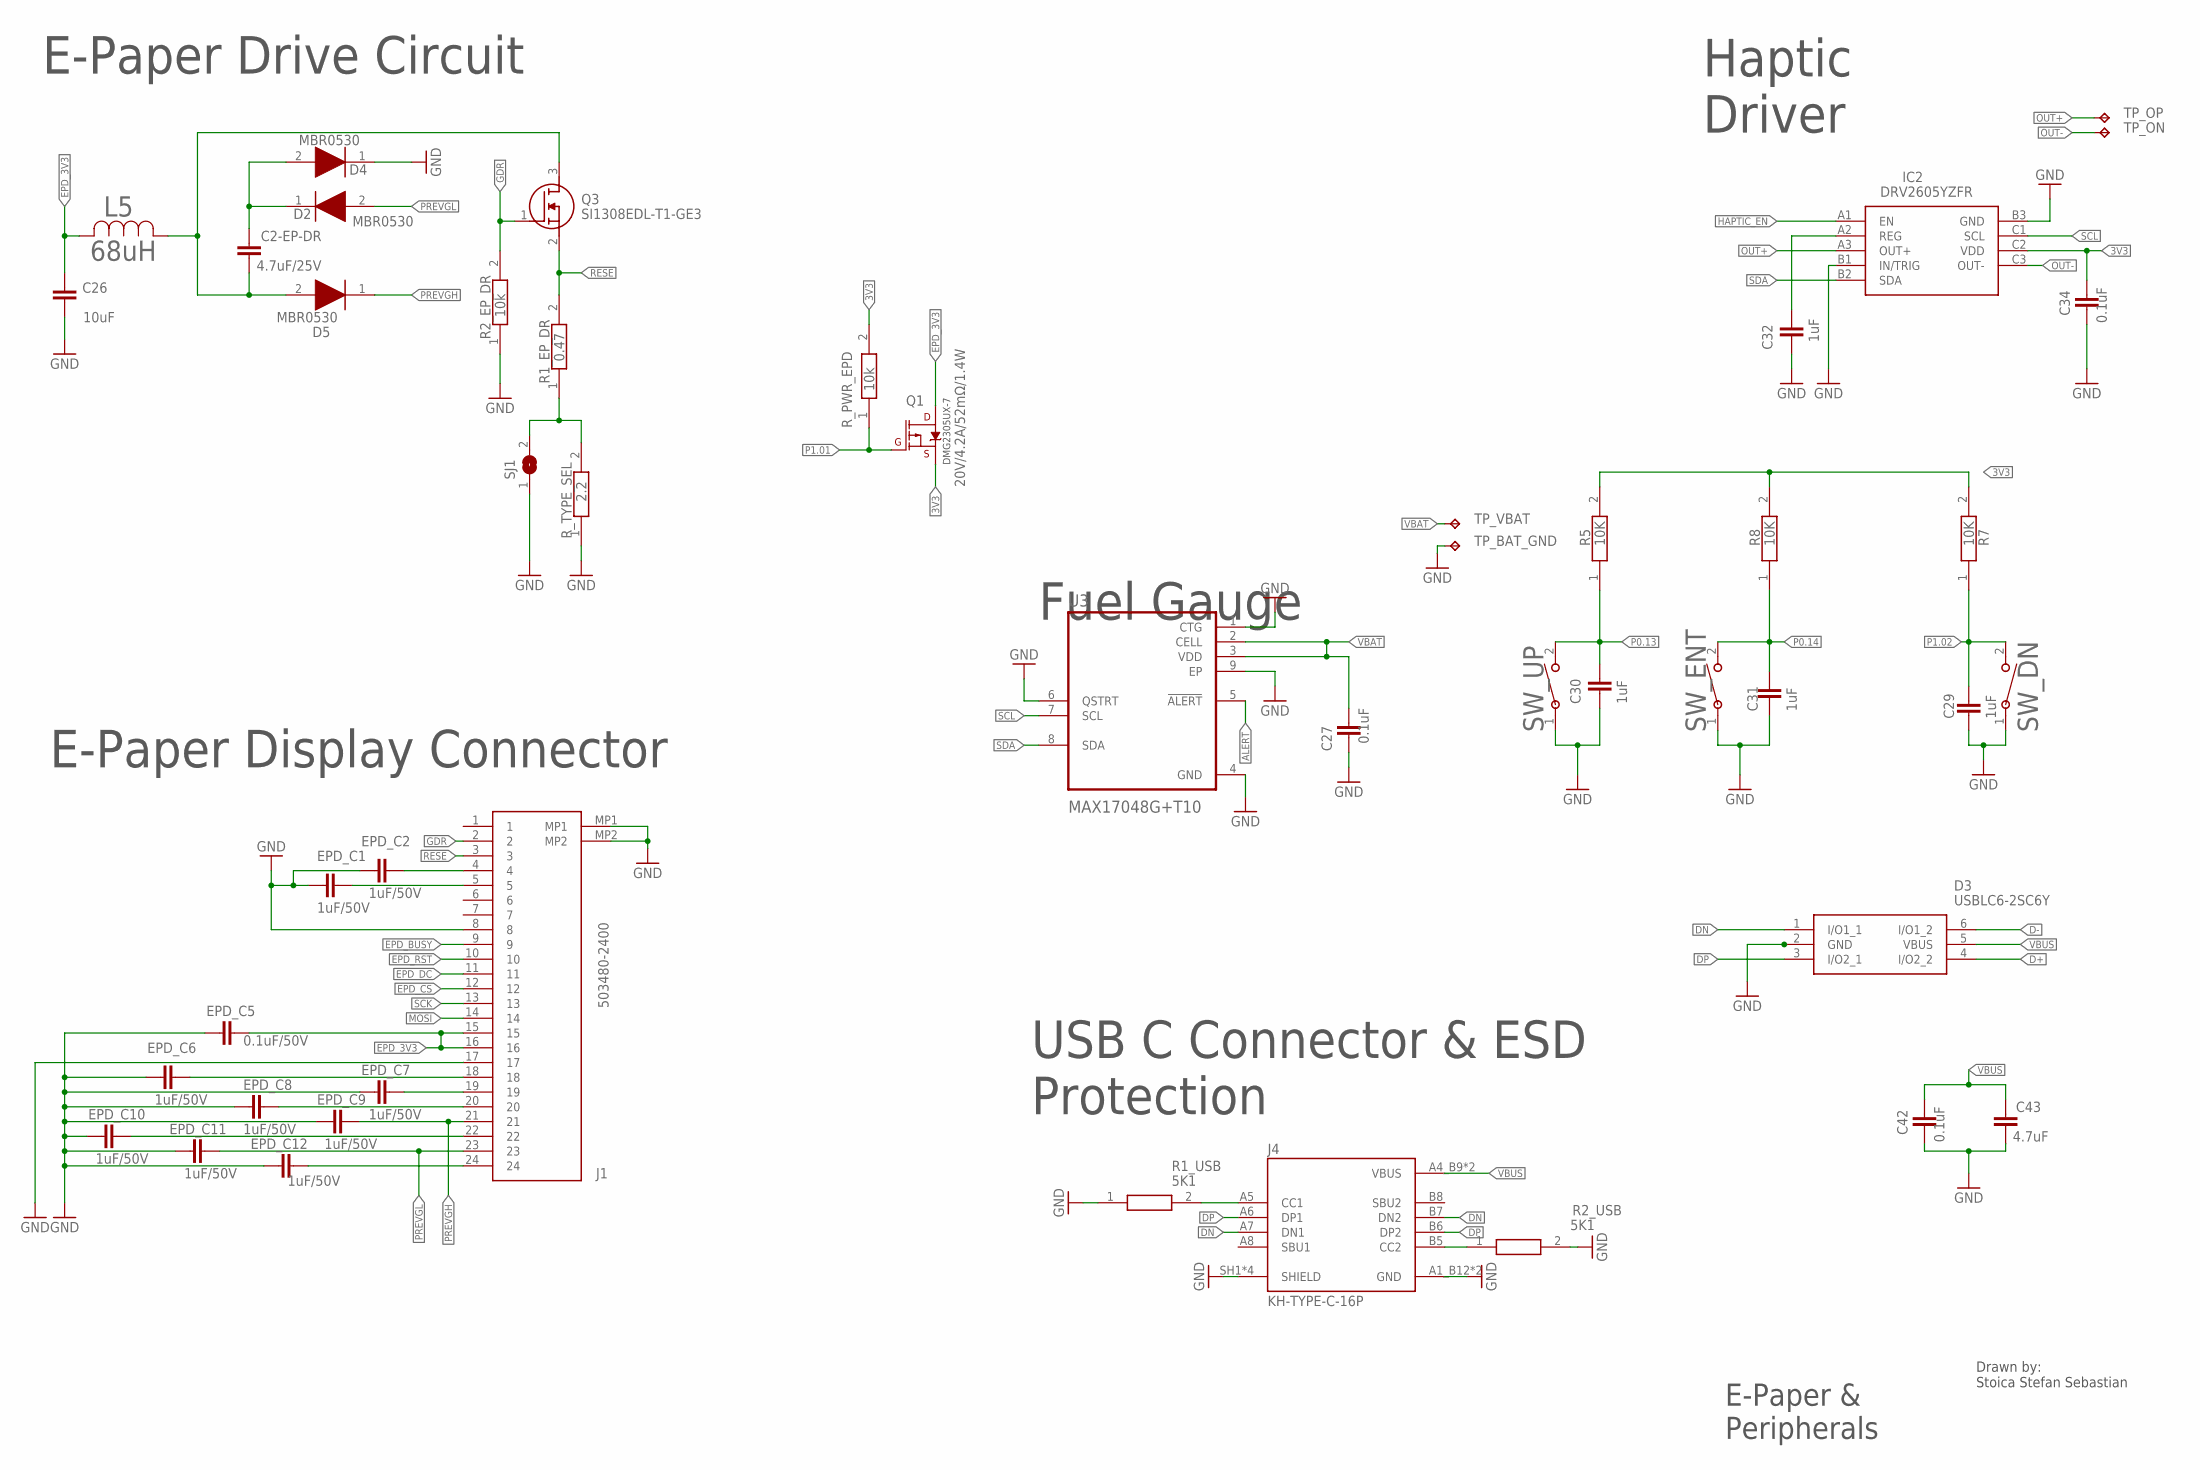
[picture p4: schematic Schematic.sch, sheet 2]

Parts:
C2-EP-DR: 4.7uF/25V; ESP32_C6_LIBRARY_1_ESP32_WROVER_EAGLE-LTSPICE_C0402
C26: 10uF; NORDIC_NRF_3_RESC0402_N
C27: 0.1uF; NORDIC_NRF_3_RESC0402_N
C29, C30, C31, C32: 1uF; NORDIC_NRF_3_RESC0402_N
C34, C42: 0.1uF; NORDIC_NRF_3_RESC0201_N
C43: 4.7uF; NORDIC_NRF_3_RESC0402_N
D2, D4, D5: MBR0530; ESP32_C6_LIBRARY_5_SOD3716X135N
D3: USBLC6-2SC6Y; ESP32_C6_LIBRARY_3_SOT95P280X145-6N
EPD_C1, EPD_C2, EPD_C6, EPD_C7, EPD_C8, EPD_C9, EPD_C10, EPD_C11, EPD_C12: 1uF/50V; NORDIC_NRF_3_RESC0402_N
EPD_C5: 0.1uF/50V; NORDIC_NRF_3_RESC0402_N
IC2: DRV2605YZFR; DRV2605YZFR_BGA9C50P3X3_144X144X62
J1: 503480-2400; 503480-2400_5034802400
J4: KH-TYPE-C-16P; KH-TYPE-C-16P_KINGHELM_KH-TYPE-C-16P
L5: 68uH; ESP32_C6_LIBRARY_2_IND_4828-WE-TPC_WRE
Q1: 20V/4.2A/52mΩ/1.4W; ESP32_C6_LIBRARY_4_ESP32_C6_LIBRARY_4_ESP32_C6_LIBRARY_4_ES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
Q3: SI1308EDL-T1-GE3; ESP32_C6_LIBRARY_6_SOT65P210X110-3N
R1_EP_DR: 0.47; CPF0201D7K68C1_0201
R1_USB, R2_USB: 5K1; CPF0201D7K68C1_0201
R2_EP_DR: 10k; CPF0201D7K68C1_0201
R5, R7, R8: 10K; CPF0201D7K68C1_0201
R_PWR_EPD: 10k; CPF0201D7K68C1_0201
R_TYPE_SEL: 2.2; CPF0201D7K68C1_0201
SJ1: ESP32_C6_LIBRARY_7_JUMPER_SJ
SW_DN: 2025-10-22_07-23-44_LIBRARY_EVP-AKE31ASW_EVP-AKE3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; 2025-10-22_07-23-44_LIBRARY_SW_EVP-AKE31A_PAN
SW_ENT: 2025-10-22_07-23-44_LIBRARY_EVP-AKE31ASW_EVP-AKE3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; 2025-10-22_07-23-44_LIBRARY_SW_EVP-AKE31A_PAN
SW_UP: 2025-10-22_07-23-44_LIBRARY_EVP-AKE31ASW_EVP-AKE3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; 2025-10-22_07-23-44_LIBRARY_SW_EVP-AKE31A_PAN
TP_BAT_GND: HECTOR_WATCH_1_TPTP20R; HECTOR_WATCH_1_TP20R
TP_ON: HECTOR_WATCH_1_TPTP20R; HECTOR_WATCH_1_TP20R
TP_OP: HECTOR_WATCH_1_TPTP20R; HECTOR_WATCH_1_TP20R
TP_VBAT: HECTOR_WATCH_1_TPTP20R; HECTOR_WATCH_1_TP20R
U3: MAX17048G+T10; ESP32_C6_LIBRARY_SON50P200X200X80-9N

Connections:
3V3: C34.1, IC2.C2 (VDD), Q1.2 (S), R5.2, R7.2, R8.2, R_PWR_EPD.2; also elsewhere on the board
ALERT: U3.5 (!ALERT); also elsewhere on the board
D+: D3.4 (I/O2_2); also elsewhere on the board
D-: D3.6 (I/O1_2); also elsewhere on the board
DN: D3.1 (I/O1_1), J4.A7 (DN1), J4.B7 (DN2)
DP: D3.3 (I/O2_1), J4.A6 (DP1), J4.B6 (DP2)
EPD_3V3: C26.1, EPD_C5.2, J1.15, J1.16, L5.2, Q1.3 (D)
EPD_BUSY: J1.9; also elsewhere on the board
EPD_CS: J1.12; also elsewhere on the board
EPD_DC: J1.11; also elsewhere on the board
EPD_RST: J1.10; also elsewhere on the board
GDR: J1.2, Q3.1 (G), R2_EP_DR.2
GND: C26.2, C27.1, C29.2, C30.1, C31.1, C32.1, C34.2, C42.2, C43.2, D3.2 (GND), D4.1 (K), EPD_C1.1, EPD_C2.1, EPD_C5.1, EPD_C6.1, EPD_C7.1, EPD_C8.1, EPD_C9.1, EPD_C10.1, EPD_C11.1, EPD_C12.1, IC2.B1 (IN/TRIG), IC2.B3 (GND), J1.8, J1.17, J1.MP1, J1.MP2, J4.A1_B12 (GND), J4.A12_B1 (GND), J4.SH1 (SHIELD), J4.SH2 (SHIELD), J4.SH3 (SHIELD), J4.SH4 (SHIELD), R1_USB.1, R2_EP_DR.1, R2_USB.2, R_TYPE_SEL.1, SJ1.1, SW_DN.1, SW_ENT.1, SW_UP.1, TP_BAT_GND.TP, U3.1 (CTG), U3.4 (GND), U3.6 (QSTRT), U3.9 (EP); also elsewhere on the board
HAPTIC_EN: IC2.A1 (EN); also elsewhere on the board
MOSI: J1.14; also elsewhere on the board
unnamed: J4.A5 (CC1), R1_USB.2
unnamed: J4.B5 (CC2), R2_USB.1
unnamed: C2-EP-DR.2, D5.2 (A), L5.1, Q3.3 (D)
unnamed: EPD_C6.2, J1.18
unnamed: EPD_C7.2, J1.19
unnamed: EPD_C8.2, J1.20
unnamed: C2-EP-DR.1, D2.1 (K), D4.2 (A)
unnamed: EPD_C2.2, J1.4
unnamed: EPD_C1.2, J1.5
unnamed: R1_EP_DR.1, R_TYPE_SEL.2, SJ1.2
unnamed: EPD_C10.2, J1.22
unnamed: EPD_C12.2, J1.24
unnamed: C32.2, IC2.A2 (REG)
OUT+: IC2.A3 (OUT+), TP_OP.TP
OUT-: IC2.C3 (OUT-), TP_ON.TP
P0.13: C30.2, R5.1, SW_UP.2; also elsewhere on the board
P0.14: C31.2, R8.1, SW_ENT.2; also elsewhere on the board
P1.01: Q1.1 (G), R_PWR_EPD.1; also elsewhere on the board
P1.02: C29.1, R7.1, SW_DN.2; also elsewhere on the board
PREVGH: D5.1 (K), EPD_C9.2, J1.21
PREVGL: D2.2 (A), EPD_C11.2, J1.23
RESE: J1.3, Q3.2 (S), R1_EP_DR.2
SCK: J1.13; also elsewhere on the board
SCL: IC2.C1 (SCL), U3.7 (SCL); also elsewhere on the board
SDA: IC2.B2 (SDA), U3.8 (SDA); also elsewhere on the board
VBAT: C27.2, TP_VBAT.TP, U3.2 (CELL), U3.3 (VDD); also elsewhere on the board
VBUS: C42.1, C43.1, D3.5 (VBUS), J4.A4_B9 (VBUS), J4.A9_B4 (VBUS); also elsewhere on the board

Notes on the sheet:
DMG2305UX-7
E-Paper Drive Circuit
E-Paper Display Connector
Fuel Gauge
Haptic Driver
E-Paper & Peripherals
Drawn by: Stoica Stefan Sebastian
USB C Connector & ESD Protection

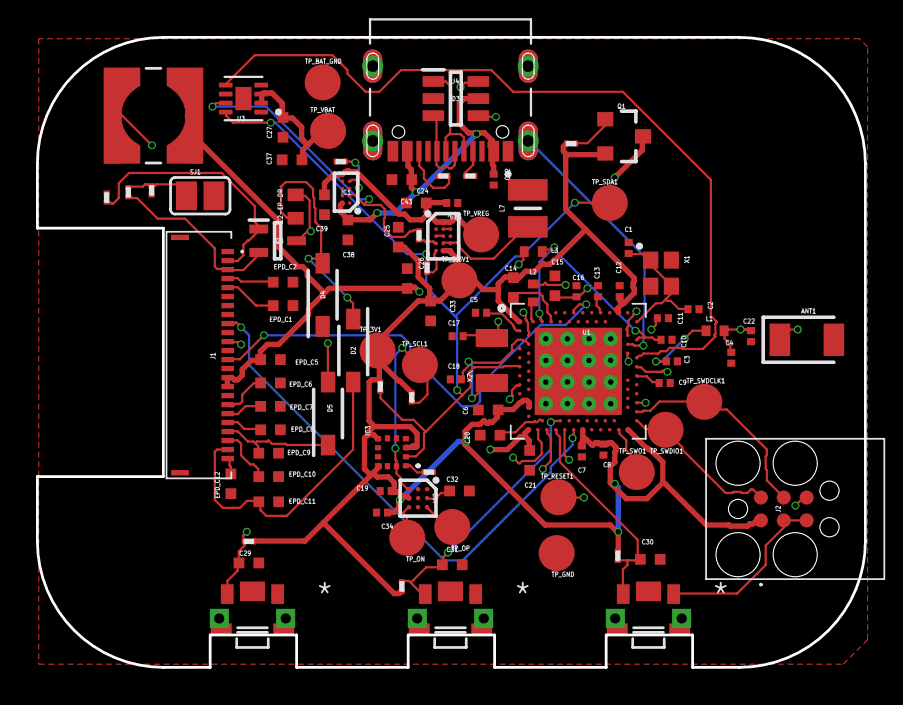
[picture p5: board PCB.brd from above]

Board: 2 copper layers, 46.0 x 35.0 mm, 105 parts (0 on the bottom side), 67 nets.

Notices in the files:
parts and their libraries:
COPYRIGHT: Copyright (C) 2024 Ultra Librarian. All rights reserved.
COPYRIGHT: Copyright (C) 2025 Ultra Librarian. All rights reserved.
